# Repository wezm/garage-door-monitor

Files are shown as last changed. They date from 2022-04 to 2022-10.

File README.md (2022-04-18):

Garage Door Monitor
===================

Build Status (https://cirrus-ci.com/github/wezm/garage-door-monitor)

<!-- TODO: Add photo here -->

A small application that monitors the state of my garage door and sends an
alert to [Mattermost] if it gets left open. The application is deployed to a
minimal custom Linux installation running on a Raspberry Pi Zero W.

The binary that monitors the garage door is in the `app` directory. It is
implemented in [Rust]. The `buildroot` directory contains the [Buildroot]
configuration for building the Raspberry Pi image. The `hardware` directory
contains a wiring diagram and 3D model for a spacer I 3D printed to mount
the reed switch to.

The system image, which includes the [kernel], [busybox], [openntp], [rsdate],
[wpa_supplicant], and the monitoring application itself is about 13Mb. It is
stored on a 256Mb micro SD card, which is the smallest I could get my hands on.
The system boots and is interactive in less than 5 seconds and runs
entirely from RAM (the microSD card is not even mounted).

[kernel]: https://www.kernel.org/
[busybox]: https://www.busybox.net/
[openntp]: https://www.openntpd.org/
[rsdate]: https://github.com/wezm/rsdate
[wpa_supplicant]: https://hostap.epitest.fi/wpa_supplicant/

Building
--------

**Note:** These instructions assume a Linux host.

To build the Linux image you will need to download and extract Buildroot as
well as install [its system requirements][reqs]. I used the [stable 2021.08
release][buildroot-dl].

Clone the repo then populate two configuration files:

* `buildroot/overlay/etc/default/garage-door-monitor` — Web-hook URL. E.g.

      GARAGE_WEBHOOK="https://example.com/"

* `buildroot/overlay/etc/wpa_supplicant.conf` — Wi-Fi configuration. E.g.

      network={
          ssid="NetworkName"
          psk="password"
      }

In the directory of the extracted Buildroot (E.g. `buildroot-2021.08`) load the
configuration:

```
make defconfig BR2_DEFCONFIG=../path/to/garage-door-monitor/buildroot/configs/garage_defconfig
```

Now point Buildroot at the external tree in this repository and kick off the
build. This will build the toolchain, kernel, and root file system. Note that
for subsequent rebuilds you can use `make` without needing to specify
`BR2_EXTERNAL` as this is remembered:

```
make BR2_EXTERNAL=../path/to/garage-door-monitor/buildroot
```

The SD card image is output to: `output/images/sdcard.img`. Write it to an SD
card with `dd` or similar. Be sure to double check the path to the SD card
device (`/dev/sdd` in this case):

```
sudo dd if=output/images/sdcard.img of=/dev/sdd bs=128k
```

Wiring
------

* A reed switch is connected between 3.3V and header pin 38 via a 10kΩ resistor. Internal pull-downs are enabled on the pin.
* The anode of a 3mm LED is connected to header pin 40 via a 220Ω resistor.
* The Pi is powered through header pins 4 (5V) and 6 (GND).

See also the Fritzing wiring diagram in `hardware`.

Licence
-------

This project is dual licenced under either of:

- Apache License, Version 2.0 ([LICENSE-APACHE](https://github.com/wezm/garage-door-monitor/blob/master/LICENSE-APACHE))
- MIT license ([LICENSE-MIT](https://github.com/wezm/garage-door-monitor/blob/master/LICENSE-MIT))

at your option.

[Buildroot]: https://buildroot.org/
[buildroot-dl]: https://buildroot.org/downloads/buildroot-2021.08.tar.bz2
[Mattermost]: https://mattermost.com/
[Rust]: https://www.rust-lang.org/
[reqs]: https://buildroot.org/downloads/manual/manual.html#requirement

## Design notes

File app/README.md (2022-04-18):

Garage Door Monitor Software
============================

This is the brains of the operation. It uses a thread per task
approach where there is a dedicated thread for each of:

- General-purpose input/output (GPIO)
  - Monitoring the door state and controlling the status LED.
- State management
  - Receives updates from the GPIO thread via a channel and detects door state
    transitions.
  - Updates the global state when a change is detected and notes the time the
    door was opened if the state transitions to open.
- Notification thread
  - Checks the global state every 5 seconds and sends a notification if the
    door has been open for more than 5 minutes.
  - Notes the notification time to prevent repeatedly sending the notification.
- HTTP server
  - Serves the web page and JSON end point.
- Main thread
  - Polls a flag every 5 seconds in order to detect signals and shutdown
    cleanly.
  - Mainly useful during development.

## Building

Buildroot normally takes care of building this application for inclusion in the
Linux image but for development. It can be built manually with `cargo build`.

It's designed in a way that it will still run if it's unable to acquire the
GPIO pins. This allowed me to build and run the rest of the functionality
directly on my Linux PC before cross-compiling for the Pi later.

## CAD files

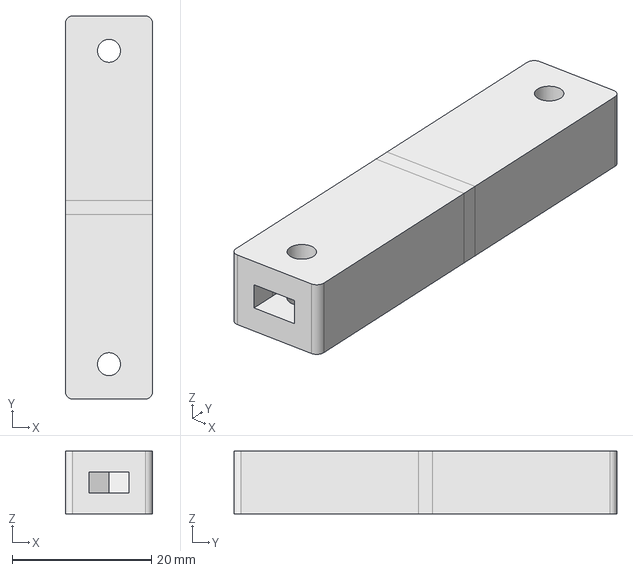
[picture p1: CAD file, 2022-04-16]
hardware/Reed Mount.FCStd
12.5 x 55.0 x 9.00 mm

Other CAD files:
hardware/Reed Mount.3mf
hardware/Reed Mount.stl

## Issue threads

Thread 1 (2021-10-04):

Buildroot

wezm, 2021-10-04:
- [x] Build an SD card image that runs from RAM
- [x] Include garage door monitor binary in image
- [x] Wi-Fi connection
- [x] Start monitor on boot
- [x] Slim down kernel
- [x] Add non-privileged user and run monitor as that user
- [x] Set root password
- [x] restart monitor binary if it exits
- [x] log with syslog
- [x] set time with ntp

wezm, 2021-10-10:
Starting point for slimming:

```
.rw-r--r--  27k wmoore 10 Oct 21:23 bcm2708-rpi-zero-w.dtb
.rw-r--r--  52k wmoore 10 Oct 21:23 bootcode.bin
.rw-r--r--   90 wmoore 10 Oct 21:23 cmdline.txt
.rw-r--r-- 1.1k wmoore 10 Oct 21:23 config.txt
.rw-r--r-- 7.3k wmoore 10 Oct 21:23 fixup.dat
drwxr-xr-x    - wmoore 10 Oct 21:23 overlays
.rw-r--r--  23M wmoore 10 Oct 21:23 rootfs.cpio.gz
.rw-r--r-- 3.0M wmoore 10 Oct 21:23 start.elf
.rw-r--r-- 6.0M wmoore 10 Oct 21:23 zImage
```

wezm, 2021-10-10:
`lsmod` with default kernel minus Bluetooth and sound card support:

```
Module                  Size  Used by    Tainted: G
ipv6                  475136 10 [permanent]
brcmfmac              303104  0
brcmutil               20480  1 brcmfmac
sha256_generic         16384  0
libsha256              20480  1 sha256_generic
cfg80211              774144  1 brcmfmac
rfkill                 32768  2 cfg80211
raspberrypi_hwmon      16384  0
bcm2835_isp            28672  0
bcm2835_codec          40960  0
v4l2_mem2mem           36864  1 bcm2835_codec
videobuf2_dma_contig    20480  2 bcm2835_isp,bcm2835_codec
bcm2835_v4l2           40960  0
bcm2835_mmal_vchiq     28672  3 bcm2835_isp,bcm2835_codec,bcm2835_v4l2
vc_sm_cma              32768  2 bcm2835_isp,bcm2835_mmal_vchiq
videobuf2_vmalloc      16384  1 bcm2835_v4l2
videobuf2_memops       16384  2 videobuf2_dma_contig,videobuf2_vmalloc
videobuf2_v4l2         32768  4 bcm2835_isp,bcm2835_codec,v4l2_mem2mem,bcm2835_v4l2
videobuf2_common       61440  5 bcm2835_isp,bcm2835_codec,v4l2_mem2mem,bcm2835_v4l2,videobuf2_v4l2
videodev              249856  6 bcm2835_isp,bcm2835_codec,v4l2_mem2mem,bcm2835_v4l2,videobuf2_v4l2,videobuf2_common
mc                     45056  6 bcm2835_isp,bcm2835_codec,v4l2_mem2mem,videobuf2_v4l2,videobuf2_common,videodev
fixed                  16384  0
uio_pdrv_genirq        16384  0
uio                    20480  1 uio_pdrv_genirq
```

wezm, 2021-10-10:
After slimming:

```
Filesystem      Size  Used Avail Use% Mounted on
/dev/loop1       15M   13M  2.2M  86% /home/wmoore/Source/buildroot/mnt
```

```
.rwxr-xr-x  27k root 11 Oct 07:54 bcm2708-rpi-zero-w.dtb
.rwxr-xr-x  52k root 11 Oct 07:54 bootcode.bin
.rwxr-xr-x   89 root 11 Oct 07:54 cmdline.txt
.rwxr-xr-x 1.1k root 11 Oct 07:54 config.txt
.rwxr-xr-x 7.3k root 11 Oct 07:54 fixup.dat
drwxr-xr-x    - root 11 Oct 07:54 overlays
.rwxr-xr-x 5.1M root 11 Oct 07:54 rootfs.cpio.gz
.rwxr-xr-x 3.0M root 11 Oct 07:54 start.elf
.rwxr-xr-x 4.5M root 11 Oct 07:54 zImage
```

wezm, 2021-10-10:
After tuning some more things off:

```
Filesystem     1K-blocks  Used Available Use% Mounted on
/dev/loop1         15310 11642      3668  77% /home/wmoore/Source/buildroot/mnt
```

```
.rwxr-xr-x  27k root 11 Oct 17:41 bcm2708-rpi-zero-w.dtb
.rwxr-xr-x  52k root 11 Oct 17:41 bootcode.bin
.rwxr-xr-x   89 root 11 Oct 17:41 cmdline.txt
.rwxr-xr-x 1.1k root 11 Oct 17:41 config.txt
.rwxr-xr-x 7.3k root 11 Oct 17:41 fixup.dat
drwxr-xr-x    - root 11 Oct 17:41 overlays
.rwxr-xr-x 4.9M root 11 Oct 17:41 rootfs.cpio.gz
.rwxr-xr-x 3.0M root 11 Oct 17:41 start.elf
.rwxr-xr-x 3.2M root 11 Oct 17:41 zImage
```

Closed 2021-10-17.

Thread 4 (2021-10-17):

Carrier board

wezm, 2021-10-17:
Design a PCB that provides:

- status LED and resistor
- terminal block for reed switch connection
- uart breakout pins
- resistor for reed switch
- terminal block for power supply. 12V is available from the existing camera
  - RC plane BEC might be a good option for a small switching regulator https://www.dx.com/p/hobbywing-5v-6v-3a-switch-mode-ultimate-bec-ubec-2005844.html

wezm, 2022-04-20:
Decided to just stick it to the wall.

Closed 2022-04-20.

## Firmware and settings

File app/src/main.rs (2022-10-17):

use io::ErrorKind;
use std::sync::atomic::{AtomicBool, Ordering};
use std::sync::{mpsc, Arc, RwLock};
use std::time::{Duration, Instant};
use std::{env, io, process, thread};

use log::{error, info, LevelFilter};
use rppal::gpio::{Gpio, InputPin, OutputPin};
use syslog::BasicLogger;

use garage_door_monitor::{alert, http, led, term_on_err, DoorState, State, Timestamp};

const DOOR_PIN: u8 = 20; // header pin 38
const LED_PIN: u8 = 21; // header pin 40
const ONE_SECOND: Duration = Duration::from_secs(1);
const SERVER_ADDR: (&str, u16) = ("0.0.0.0", 8888);
const USER: &str = "_garage";
const GROUP: &str = "_garage";

fn main() -> Result<(), io::Error> {
    // Set up logging to syslog
    let formatter = syslog::Formatter3164 {
        facility: syslog::Facility::LOG_USER,
        hostname: None,
        process: env!("CARGO_PKG_NAME").into(),
        pid: 0,
    };
    let log_res = syslog::unix(formatter)
        .map_err(|err| format!("unable to connect to syslog: {:?}", err))
        .and_then(|logger| {
            log::set_boxed_logger(Box::new(BasicLogger::new(logger)))
                .map(|()| log::set_max_level(LevelFilter::Info))
                .map_err(|err| format!("unable to set logger: {:?}", err))
        });
    if let Err(err) = log_res {
        eprintln!("{}", err);
    }

    let term = Arc::new(AtomicBool::new(false));
    signal_hook::flag::register(signal_hook::consts::SIGINT, Arc::clone(&term))?;
    signal_hook::flag::register(signal_hook::consts::SIGTERM, Arc::clone(&term))?;

    let (tx, rx) = mpsc::channel();
    let state = Arc::new(RwLock::new(State {
        door_state: DoorState::Unknown,
        timestamp: Timestamp::None,
        notified_at: None,
    }));
    let pins = setup_gpio();
    let webhook_url = env::var("GARAGE_WEBHOOK").map_err(|err| {
        error!("Unable to read GARAGE_WEBHOOK: {}", err);
        io::Error::new(ErrorKind::Other, err)
    })?;
    let mut threads = Vec::new();

    // If running as root drop privs to garage user.
    // We need root setup_gpio so this is done after that.
    if unsafe { libc::geteuid() } == 0 {
        match drop_root::set_user_group(USER, GROUP) {
            Ok(()) => info!("Privileges dropped"),
            Err(err) => {
                error!("Unable to drop root privileges: {}", err);
                std::process::exit(1);
            }
        }
    }

    // GPIO thread
    // The GPIO thread is only spawned if we were able to acquire the pins
    // If a physical inspection of the device shows no flashing then this state should be obvious.
    match pins {
        Ok((door, mut led)) => {
            let term = Arc::clone(&term);
            let thread = thread::spawn(move || {
                while !term.load(Ordering::Relaxed) {
                    let door_state = door.read().into();
                    term_on_err!(tx.send(door_state), &term);

                    match door_state {
                        DoorState::Closed => led::flash(&mut led, 1),
                        DoorState::Open => led::flash(&mut led, 2),
                        DoorState::Unknown => led::flash(&mut led, 3),
                    }
                    std::thread::sleep(ONE_SECOND);
                }
                info!("GPIO thread exiting");
            });
            threads.push(thread);
        }
        Err(err) => {
            error!("Unable to set up GPIO: {}", err)
        }
    }

    // State management thread
    {
        let term = Arc::clone(&term);
        let state = Arc::clone(&state);
        let thread = thread::spawn(move || {
            while !term.load(Ordering::Relaxed) {
                if let Ok(door_state) = rx.recv_timeout(ONE_SECOND) {
                    let current_state = { *term_on_err!(state.read(), &term) };
                    let new_state = match (door_state, current_state.timestamp) {
                        // Closed to open transition
                        (DoorState::Open, Timestamp::None | Timestamp::ClosedAfter(_)) => State {
                            door_state,
                            timestamp: Timestamp::OpenSince(Instant::now()),
                            notified_at: None,
                        },
                        // Open to closed transition
                        (DoorState::Closed, Timestamp::OpenSince(open_since)) => {
                            let now = Instant::now();
                            let open_for = now.duration_since(open_since);
                            State {
                                door_state,
                                timestamp: Timestamp::ClosedAfter(open_for),
                                notified_at: None,
                            }
                        }
                        _ => State {
                            door_state,
                            ..current_state
                        },
                    };
                    if new_state != current_state {
                        *term_on_err!(state.write(), &term) = new_state;
                    }
                }
            }
            info!("state management thread exiting");
        });
        threads.push(thread);
    }

    // Notification thread
    {
        let term = Arc::clone(&term);
        let state = Arc::clone(&state);
        let thread = thread::spawn(move || {
            while !term.load(Ordering::Relaxed) {
                // I don't want to hold the lock while the notification is sent. If it's slow
                // then it will block other things from happening, however there could be a
                // read-modify-write case if the state is updated while the notification is
                // sent. Since we clear notified_at when detecting and opening this is ok.
                let current_state = { *term_on_err!(state.read(), &term) };
                let maybe_sent = alert::maybe_send(
                    current_state.timestamp,
                    current_state.notified_at,
                    &webhook_url,
                );
                if maybe_sent.is_some() {
                    // notification was sent, update state
                    let mut current_state = term_on_err!(state.write(), &term);
                    current_state.notified_at = maybe_sent
                }

                thread::sleep(5 * ONE_SECOND);
            }
            info!("notification thread exiting");
        });
        threads.push(thread);
    }

    // Start HTTP server
    let server = match http::Server::new(SERVER_ADDR) {
        Ok(server) => Arc::new(server),
        Err(err) => {
            error!(
                "Unable to start http server on {}:{}: {}",
                SERVER_ADDR.0, SERVER_ADDR.1, err
            );
            process::exit(1);
        }
    };
    info!("http server running on {}:{}", SERVER_ADDR.0, SERVER_ADDR.1);

    // Handle HTTP requests
    {
        let state = Arc::clone(&state);
        let server = Arc::clone(&server);
        let thread = thread::spawn(move || {
            server.handle_requests(state);
            info!("server thread exiting");
        });
        threads.push(thread);
    }

    // Wait for signals to exit
    while !term.load(Ordering::Relaxed) {
        std::thread::sleep(5 * ONE_SECOND);
    }
    server.shutdown();

    for thread in threads {
        let _ = thread.join();
    }

    Ok(())
}

fn setup_gpio() -> rppal::gpio::Result<(InputPin, OutputPin)> {
    let gpio = Gpio::new()?;
    let door_pin = gpio.get(DOOR_PIN)?.into_input_pulldown();
    let led_pin = gpio.get(LED_PIN)?.into_output();
    Ok((door_pin, led_pin))
}

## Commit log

2021-09-10 Add base raspberrypi0w defconfig
    From buildroot-2021.08
2021-10-04 Make http server run on background thread
2021-10-04 Exclude the buildroot dir from GitHub's repo language analysis
    It makes it look like the project is implemented in shell script, which
    is not the case.
2021-10-04 Make S99garage executable 🤦
2021-10-10 linux: Disable sound and multimedia devices
2021-10-10 linux: Disable MD (LVM/RAID) and MMC block devices
2021-10-10 linux: Disable multiple network devices including Bluetooth
2021-10-10 linux: Disable Ethernet devices and IP components built as modules
2021-10-10 linux: Disable lots more things
    - Network file sytems
    - More disk file systems
    - netfilter
    - net sched
    - input devices (keyboard, mice, joysticks, etc)
2022-04-16 Add 3D printed reed switch mount
    [Reed Mount.3mf, Reed Mount.FCStd, Reed Mount.stl]
2022-04-16 Add wiring notes to README
2022-04-18 Add Fritzing wiring diagram
    [Wiring.fzz]
